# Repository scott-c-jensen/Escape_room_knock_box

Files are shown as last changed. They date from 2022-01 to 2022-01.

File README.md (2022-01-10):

# Escape_room_knock_box
An arduino controlled electronic lock box that stays locked until knocked in a specific pattern. This project contains the code, wiring diagram and a 3d model for mounting. In the end it will look something like this.

## Here is the box:



The electronics in the lid of the box enclosed in a 3d print:



Removing the 3d printed cover:



Finally an up close picture of the electronics:



## Code Base:
The code is written in arduino and has a number of global variables to control the sensitivity and knock pattern for the code. No special requirements for setup as there are no other dependencies. 

## Electronics:
Here is the wiring diagram which includes the following:
  - Arduino nano
  - one 8x AA/AAA battery holder (or two 4x wired as shown in the diagram)
  - one TIP 120 transistor
  - one 1N4001 diode
  - one Piezo electric sensor
  - one 2.2 kΩ resistor
  - one solenoid lock (9-12V operation normally closed)
  - (optional) one protoboard 



The wiring schematic is also shown here (though the TIP 120 schematic from adafruit appears unreasonably large in the Fritzing program). The drawing is also included in the repo.



## 3D Printing/construction:
For the 3d printed parts, glue the base plate to the top of the lid with the nuts (#4 and #6) captivated against the top of the box. There are spaces for 4 nuts but 2 opposite corners is enough to hold the electronics. After gluing, you will need to screw a hole for a #2 screw in the protoboard to screw the board to the base plate. The cap will then go on using #6 screws.

Also note that the latch mechanism needs something to catch onto when closed. This can be a simple thin sheet glued to the side of the box base. In my case the box

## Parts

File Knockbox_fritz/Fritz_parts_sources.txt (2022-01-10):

So there are a few of the parts in fritzing that I found form external sources:
 - TIP120 transisitor from Adafruit
 - The piezo from here: http://omnigatherum.ca/wp/?p=262.

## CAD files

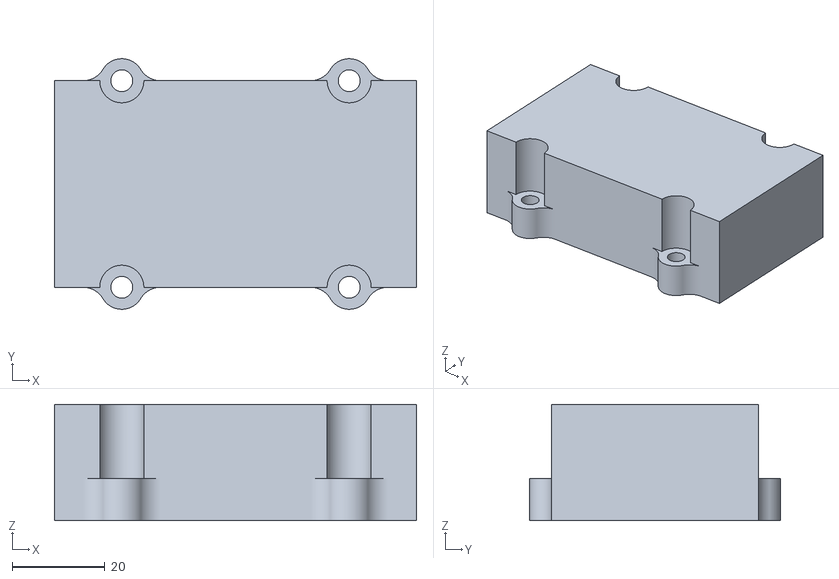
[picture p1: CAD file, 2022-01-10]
Knock Box STLs/Top - Knock box top.stl
78.0 x 54.0 x 25.0

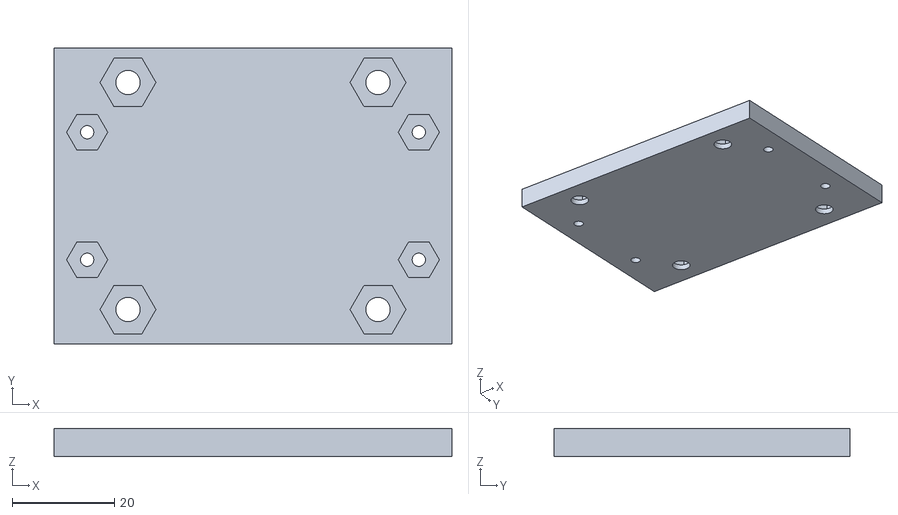
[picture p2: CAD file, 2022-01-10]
Knock Box STLs/Base Plate - Knock Box.stl
78.0 x 58.0 x 5.50

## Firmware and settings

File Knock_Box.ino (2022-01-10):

/** 
 * KNOCK BOX PROGRAM
 * @author Scott C Jensen
 * @version 4
 * 
 * @section Here is the program that checks for knocks (rising edge signal) has the right sequence of intervals (pattern) between knocks
 * If this is for a song, then the time between the start of each note is what is measured. 
 * So a quarter note, two eigth notes and a half note would result in (2,1,1) Note the last note is the last knock and doesn't need an interval
 * Once the correct sequence is found a pin is set to high to unlock the box
 *
 *  Determining if the knock sequence is ok
 *  - Identify the knocks
 *  - Identify the normalized time between knocks and compare with set signals with max difference and average difference between the normalized knocks
 * 
 * Note: The sequence is normalized so that means that tempo doesn't matter as it is all relative measurements 
 * 
 * Optional Future work
 *  - Identify ways to reduce box shaking as a knocks (particulary when something is inside)
 *       - Normalizing the knock strength by the max intensity in sequence didn't work.
 *       - Perhaps signal processing or ML could help here.
 *  - Find a way to compensate for deadend zones (ie I would like to glue the batteries in the top of the box but this dampens knocks in that region of the box)
 *       - Unfortunately I think the best way around this is to create a 3d printed platform that keeps all components offset from the lid. Shouldn't be hard.
 *  - Add a self calibration function that can be used to calibrate the background threshold for what is determined to be a knock vs picking it up shaking etc
 *       - This would require a standardized way of knocking the box to calibrate it.
 * 
 * Notes:
 * So I am NOT changing the knock rejection criterion from the max/average difference to the max/average percent difference
 *      - The problem with the percent difference is that it strongly weights exact timing of short notes (small error in small numbers)
 *      - The issue with max difference is that it will typically look at the longest note interval (if the knock pattern is close to correct)
 *              - This is likely a second order issue after the optional future work code
*/    

const int ledPin = LED_BUILTIN;          
const int lockPin = 2;         // solenoid pin
const int knockSensor = 7;     // piezo pin

//Global variables for setup
int threshold = 40;                       // Minimum signal from the piezo to register as a knock. 60 is probably the highest I would go
int background_thresh = threshold/2;      //Signal must drop below this to reset for next knock (ie the first knock is done)
const int beat = 100;                           // Determines the resolution of normalized intervals. If the smallest interval is 100 then the resolution of the normalized knock interval will be 1/100th.
const int max_knock_diff = .55*beat;        // If an individual knock is off by this number of beats it wont unlock (2/3 beat is a low sensitivity)
const int averagemax_knock_diff = .25*beat; // Average number of beats the entire sequence can be off (NOTE: scales with the number of notes, not length of time)
const int lockOpenTime = 3000;         // How long the lock opens in ms
const int num_intervals = 6;              // Maximum number of knock intervals to listen for NOTE: This is (number of knocks - 1).

int secretCode[num_intervals] = {2*beat, 1*beat, 1*beat, 1*beat, 1*beat, 3*beat};  // Interval between notes with the smallest interval being one "beat" ie
int norm_knock_interval[num_intervals]; // knock intervals normalized to the same length as secretCode
int knock_intervals[num_intervals];    // Intervals between recorded knocks
int knockSensorValue = 0;            // Last reading of the knock sensor.
int prev_knock_time = 0;            // time at which a high value is above the threshold

void blinkLED(){
      digitalWrite(ledPin, HIGH);
      delay_after_knock();
      digitalWrite(ledPin, LOW);
}

void update_array( int new_val){
  /** Shifts all intervals back one index, drops the last and fills the first with new_val
  * @new_val is the interval between the previous and the newest knock in ms
  */
    for (int i=0; i<(num_intervals-1); i++){
      knock_intervals[i]=knock_intervals[i+1];
    }
    knock_intervals[num_intervals-1] = new_val;
}

void update_knock_intervals(){
  /** Gets difference between current time and previous knock
  * sends interval to update knock_intervals
  */
  update_array(int(millis())-prev_knock_time);
  prev_knock_time = int(millis());          
}

int sum_array(int array[num_intervals]){
  /** Sums elements of an array only including the first num_intervals elements
  * @array is the array to be summed, length num_intervals
  */
  int sum = 0;
  for (int i=0;i<num_intervals;i++){
    sum +=array[i]; //Finds the entire time for knock sequence
  }
  return sum;
}

int get_max_knock_diff(int knock_array[num_intervals]){
  /** Finds the max difference between the input array and expected knock pattern 
  * @Knock_array is the array of length num_intervals that is compared to the the secret code
  */
  int max_diff = 0;
  int diff;
  for (int i=0;i<num_intervals;i++){
    diff = abs(knock_array[i]-secretCode[i]);
    if (diff > max_diff){
      max_diff = diff;
    }
  }
  return max_diff;
}

int get_mean_diff(int knock_array[num_intervals]){
  /** Finds the mean difference between the input array and expected knock pattern 
  * @Knock_array is the array of length num_intervals that is compared to the the secret code
  */
  int diff_sum = 0;              
  for (int i=0;i<num_intervals;i++){
    diff_sum+=abs(knock_array[i]-secretCode[i]);
  }
return(diff_sum/num_intervals);
}

void check_intervals(){
  /** Checks if intervals are correct */
  if (is_secret_code()){
    delay(75);
    unlock_door(lockOpenTime);
  }
}

bool is_secret_code(){
  /** Compares the knock interval to secretCode to verify if they are close enough. 
  * This is achieved by:
  *   - normalizing the knock intervals to the same length as the secret code
  *   - Finding the max/mean difference between knock intervals and secret code 
  *   - Verifying max/mean are within tolerances
  * Returns bool
  */
  int interval_sum;
  int mean_interval_diff;
  int max_interval_diff;
  
  interval_sum = sum_array(knock_intervals);
  norm_array(sum_array(secretCode),interval_sum);
  
  //Get normalized values
  max_interval_diff = get_max_knock_diff(norm_knock_interval);
  mean_interval_diff = get_mean_diff(norm_knock_interval);

  report_diagnostics(max_interval_diff, mean_interval_diff);
  // It can also fail if the whole thing is too inaccurate.
  if  ((is_average_diff_ok(mean_interval_diff)) && (is_max_diff_ok(max_interval_diff))){
    Serial.println("Victory!");
    return true;
  }
  return false;
}

void norm_array(int output_sum, int array_sum){
  /** Normalizes the array such that the sum of the array matches output_sum
  * @output_sum is an int output sum of the normalized array
  * @array_sum is the current_sum of the array
  * Currently updates a global variable used elsewhere
  */
  for (int i=0;i<num_intervals;i++){
    norm_knock_interval[i]=map(knock_intervals[i],0,array_sum,0,output_sum);
  }
}

bool is_max_diff_ok(int max_diff){
  /** Verifies that the max diff is within globally set limits 
  * @max_diff is the max diff betwen the normalized knock intervals and secret code
  */
  if (max_diff>max_knock_diff){
    Serial.println(" Bad Max Knock");
    return false;
  }
  return true;
}

bool is_average_diff_ok(int avg_diff){
  /** Verifies that the average diff is within globally set limits 
  *  @avg_diff is the avg diff betwen the normalized knock intervals and secret code
  */
  if (avg_diff > averagemax_knock_diff){
    Serial.println(" Bad Average Knock");
    return false; 
  }
  return true;
}

void report_diagnostics( int max_diff, int mean_diff ){
  /** Reports intervals and diffs
  * @max_diff is the max diff betwen the normalized knock intervals and secret code
  * @avg_diff is the avg diff betwen the normalized knock intervals and secret code
  */
  Serial.print("Secret Code: ");
  print_array(secretCode);
  Serial.print("Your Knock Code: ");
  print_array(knock_intervals);
  //print_array(norm_knock_interval);
  Serial.println((String)" Max Single Knock Diff: "+ max_diff);
  Serial.println((String)" Average Knock Differences: "+mean_diff);
}

void print_array(int a[num_intervals]){
  /** prints array a 
  * @a is an array of length num_intervals
  */
  for (int i=0; i < num_intervals; i++){ 
    if (i<num_intervals-1){
      Serial.print((String)a[i]+", ");
    }
    else{
      Serial.println(a[i]);
    }
  }
}

void delay_after_knock(){
  /** Waits for two analog read values to be below the background threshold
  * This essentially waits for the knock signal to die off for each knock */
  int prev_val=0;
  int val=analogRead(knockSensor);

  while ((val>background_thresh)||(prev_val>background_thresh)){
    delay(10);
    prev_val = val;
    val = analogRead(knockSensor);
  } 
}

void unlock_door(int delayTime){
  /** Sends signal to unlock the box for a set amount of time
  * @delayTime - Amount of time that the box is open in ms
  */
  digitalWrite(ledPin, HIGH);
  digitalWrite(lockPin, HIGH);
  delay(delayTime);
  digitalWrite(lockPin, LOW);
  digitalWrite(ledPin, LOW);  
  delay(500);   // Delay to avoid starting the next knock sequence.
}

bool is_valid_knock(){
  /** Verifies input signal for the knock sensor is above threshold and is then considered a "knock"
  */
  knockSensorValue = analogRead(knockSensor);
  if (knockSensorValue >= threshold){
    Serial.println(knockSensorValue);
    return true;
  }
  return false;
}

void setup() {
  pinMode(ledPin, OUTPUT); 
  pinMode(lockPin, OUTPUT);
  unlock_door(500);     // Unlock the door on startup for diagnostics
  delay(500);          // Delay to avoid starting the next knock sequence.
  Serial.begin(9600);
}

void loop() {
  /** Listen for a knock, when knock is heard, update intervals and check pattern. 
  */
  if (is_valid_knock()){
    update_knock_intervals();
    check_intervals();
  }
  delay(1);
} 
